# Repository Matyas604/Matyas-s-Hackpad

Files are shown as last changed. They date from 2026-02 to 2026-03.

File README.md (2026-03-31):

# Matyas-s-Hackpad
It has 8 keys (7 switches + rotary encoder switch), a rotary encoder, and an OLED display. Each key is backlit with SK6812 MINI-E LEDs. It uses [QMK](https://qmk.fm/) firmware and VIA.

## CAD Model:
Everything is connected by four M3x16mm screws and M3x5mx4mm heatset inserts. The case is printed in two parts, top and bottom.
<p align="center">
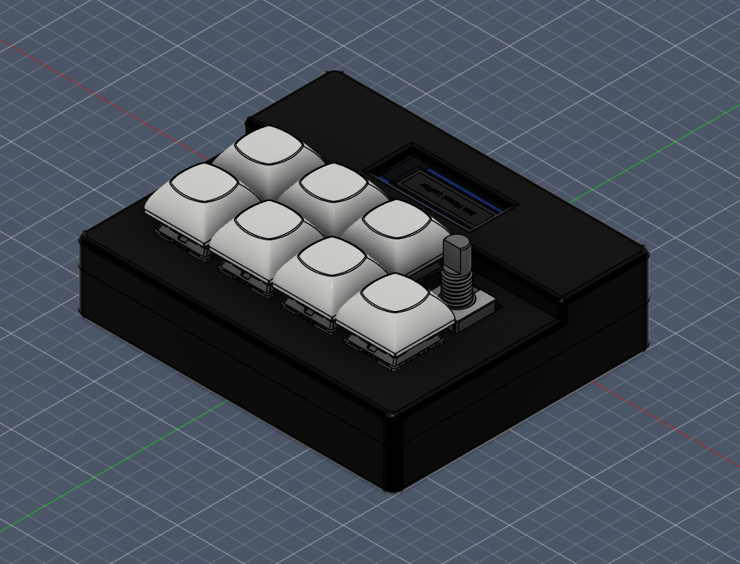
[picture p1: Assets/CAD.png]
Hackpad CAD
  
</p>
<p align="center">
  <strong>Made in Fusion360</strong>
</p>

## PCB:
<p align="center">
  Schematic
</p>
<p align="center">
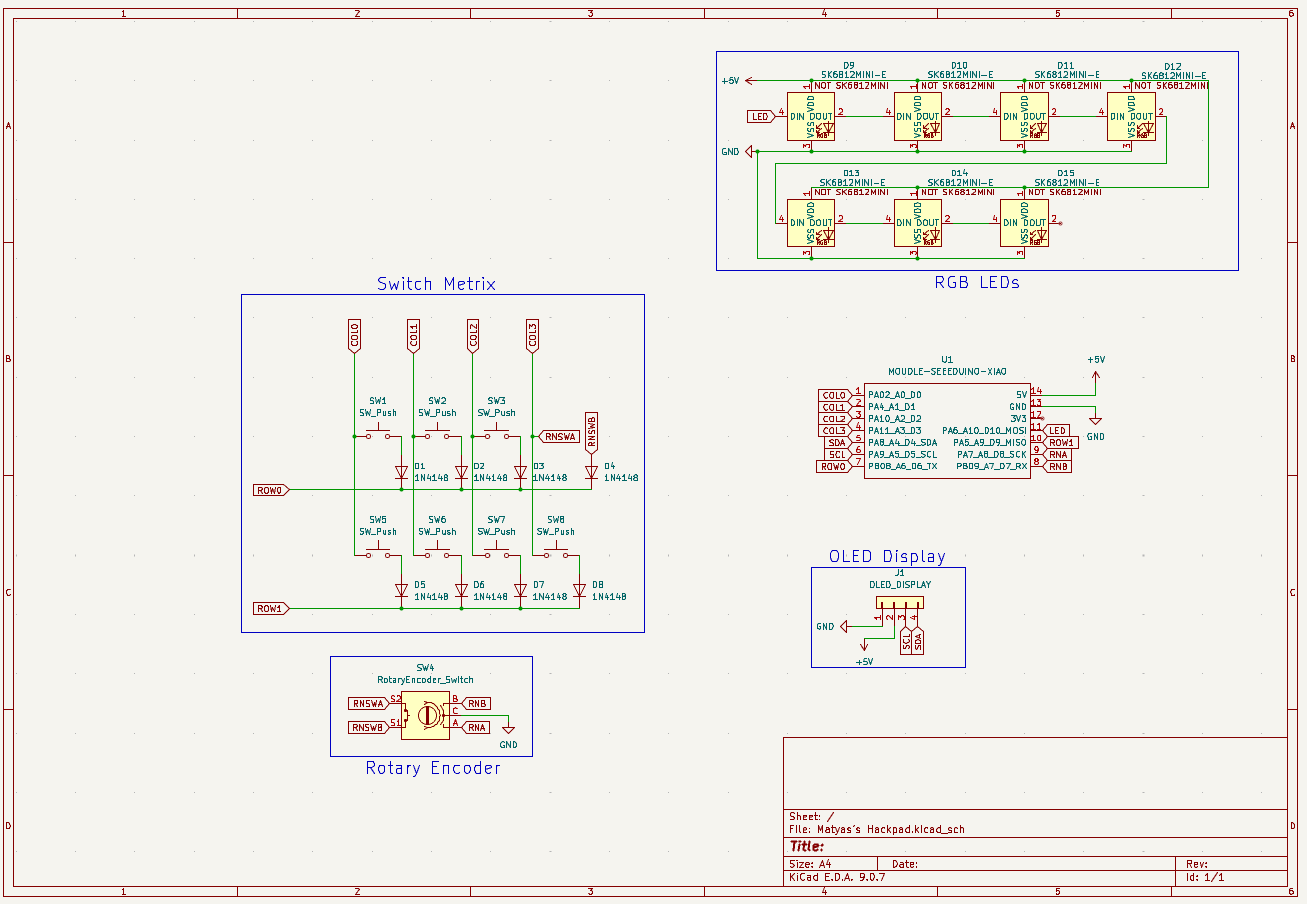
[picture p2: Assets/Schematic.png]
Hackpad schematic
  
</p>
<br>
<p align="center">
  PCB
</p>
<p align="center">
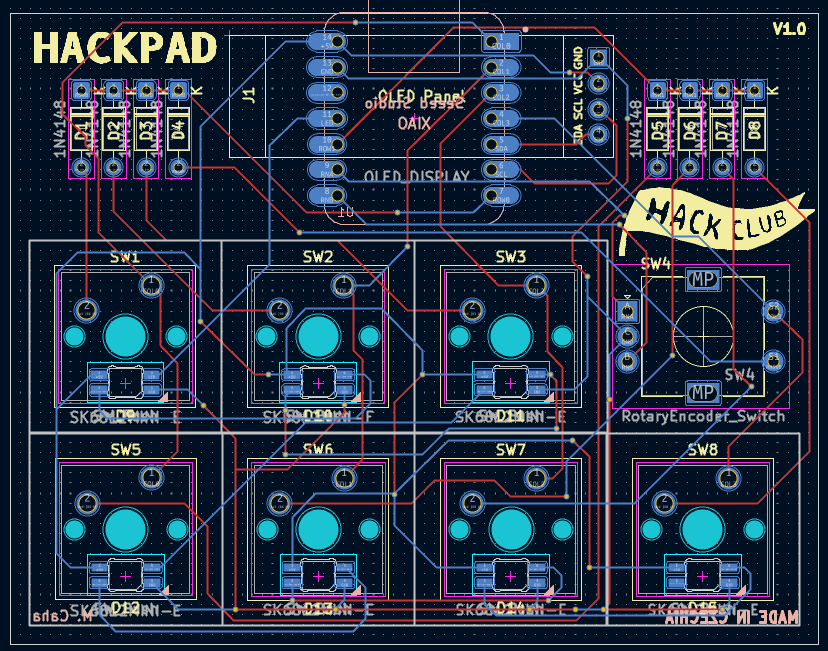
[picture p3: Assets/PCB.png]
Hackpad PCB
  
</p>
<p align="center">
  <strong>Made in KiCad</strong>
</p>

## Case:
<p align="center">
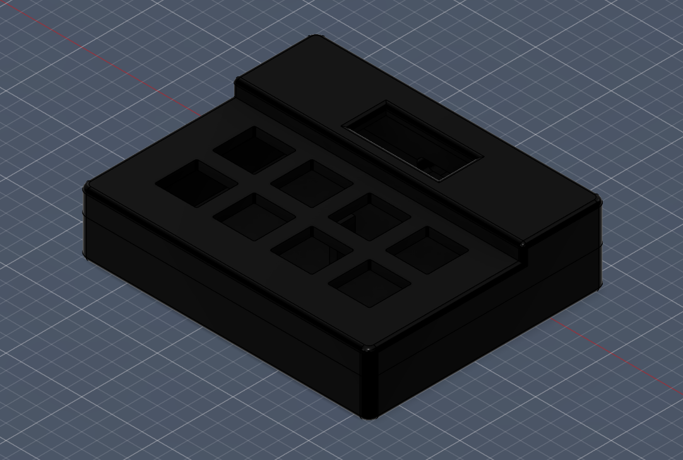
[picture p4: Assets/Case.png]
Hackpad Case
  
</p>
<p align="center">
  <strong>Made in Fusion360</strong>
</p>

## Firmware:
This Hackpad uses [QMK](https://qmk.fm/) firmware. Everything can be controlled in VIA. I have five layers set up, and I can assign anything to each one. I switch between them with a single switch. My layers are Main, Media, HA (shortcuts for Home Assistant), Game, and Other. I can also adjust the effects, speed, brightness, and backlight colors of LEDs directly from VIA. The OLED display shows the name of the current page.
<p align="center">
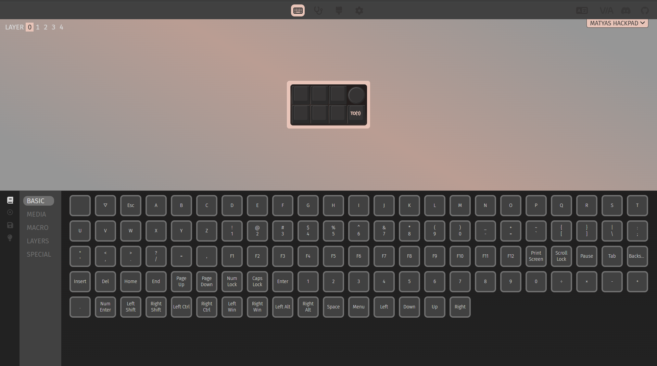
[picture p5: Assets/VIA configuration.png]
VIA Keymap Configuration
  
</p>

<p align="center">
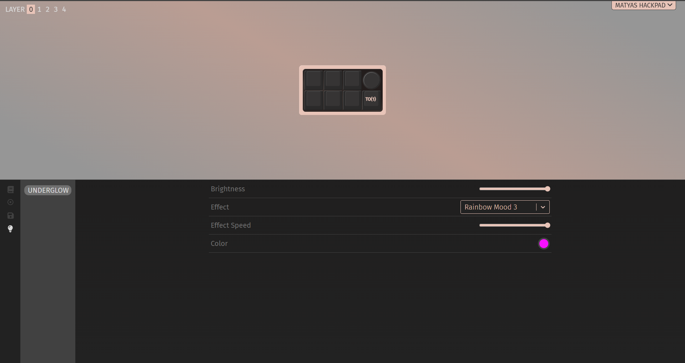
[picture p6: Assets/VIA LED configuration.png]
VIA Underglow Lighting
  
</p>

## Final result:
<p align="center">
  Hackpad Final
  Hackpad Final
</p>
<p align="center">
  <a href="https://www.youtube.com/shorts/VJYHFeJ_mRk">
    🎬 <b>HACKPAD DEMO HERE</b> 🎬
  </a>
</p>
I really enjoyed designing and building the hackpad. It was the very first project I designed from start to finish. I learned how to use Fusion and create PCBs in KiCAD. There were a few mistakes in the model, but they weren’t that big. I made only one mistake during assembly: I soldered the rotary encoder on the other side of the board, and when I desoldered it, I snapped off a leg, but there were two in the kit, so it was fine. The programming was a bit difficult, but in the end, I managed to do what I wanted. 

## BOM:
Here is everything you need to create this Hackpad:
| Component | Amount |
| :--- | :---: |
| **Seeed XIAO RP2040** | 1x |
| **MX-Style switches** | 7x |
| **1N4148 Diodes** | 8x | 
| **EC11 Rotary encoder** | 1x |
| **0.91 inch OLED display** | 1x |
| **DSA keycaps** | 7x |
| **SK6812 MINI-E LED** | 7x |
| **M3x16mm screw** | 4x |
| **M3x5mx4mm heatset insert** | 4x |
| **Case** (2 printed parts) | 1x |
| **PCB** | 1x |

<hr>

<p align="center">
  Made with ❤️ by <a href="https://github.com/Matyas604">@Matyas604</a>
</p>

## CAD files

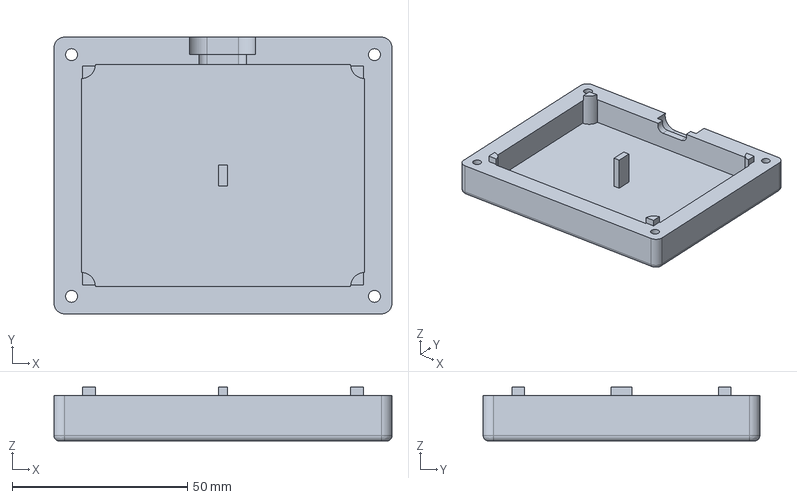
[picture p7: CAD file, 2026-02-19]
Production/Bottom part.step
96.5 x 79.0 x 15.4 mm

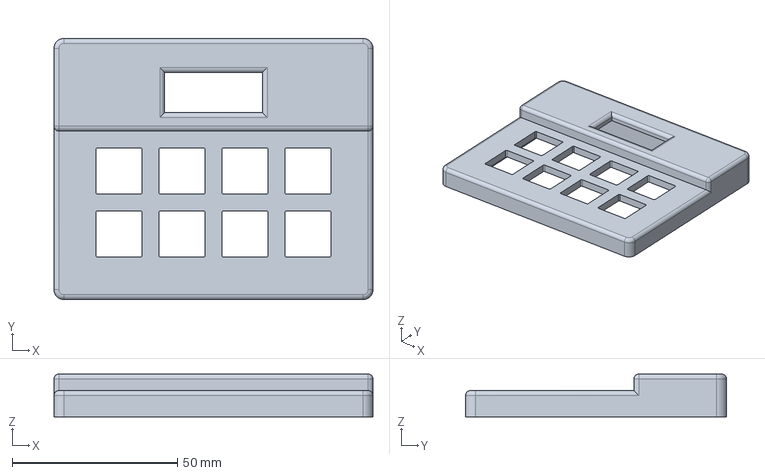
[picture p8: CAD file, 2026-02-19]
Production/Top part.step
96.4 x 79.0 x 13.0 mm

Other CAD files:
CAD/Matyas's Hackpad V1.step

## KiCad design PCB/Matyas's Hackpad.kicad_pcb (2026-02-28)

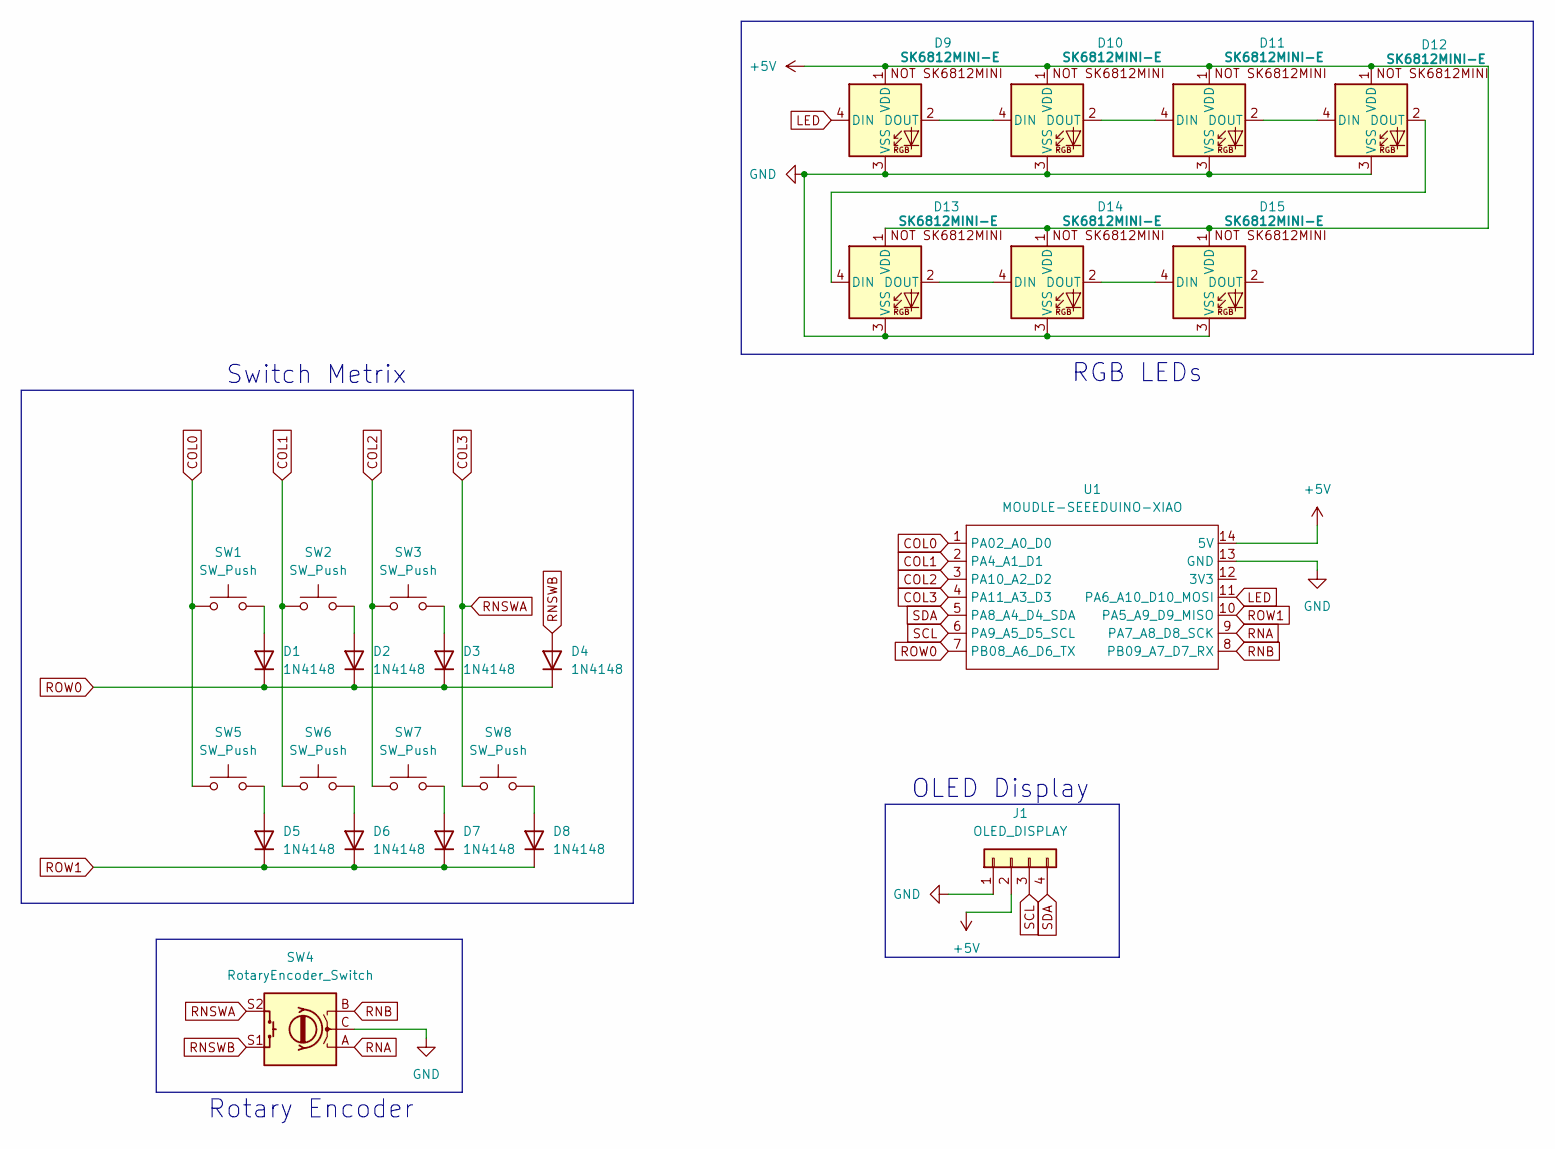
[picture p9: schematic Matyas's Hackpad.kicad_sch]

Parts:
D1, D2, D3, D4, D5, D6, D7, D8: 1N4148; D_DO-35_SOD27_P7.62mm_Horizontal
D9, D10, D11, D12, D13, D14, D15: SK6812MINI-E; SK6812MINI-E_fixed
J1: OLED_DISPLAY; SSD1306-0.91-OLED-4pin-128x32
SW1, SW2, SW3, SW5, SW6, SW7, SW8: SW_Push; SW_Cherry_MX_1.00u_PCB
SW4: RotaryEncoder_Switch; RotaryEncoder_Alps_EC11E-Switch_Vertical_H20mm
U1: MOUDLE-SEEEDUINO-XIAO; XIAO-Generic-Hybrid-14P-2.54-21X17.8MM

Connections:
+5V: D9.1 (VDD), D10.1 (VDD), D11.1 (VDD), D12.1 (VDD), D13.1 (VDD), D14.1 (VDD), D15.1 (VDD), J1.2, U1.14 (5V)
COL0: SW1.1, SW5.1, U1.1 (PA02_A0_D0)
COL1: SW2.1, SW6.1, U1.2 (PA4_A1_D1)
COL2: SW3.1, SW7.1, U1.3 (PA10_A2_D2)
COL3: SW4.S2, SW8.1, U1.4 (PA11_A3_D3)
GND: D9.3 (VSS), D10.3 (VSS), D11.3 (VSS), D12.3 (VSS), D13.3 (VSS), D14.3 (VSS), D15.3 (VSS), J1.1, SW4.C, U1.13 (GND)
LED: D9.4 (DIN), U1.11 (PA6_A10_D10_MOSI)
unnamed: D1.2 (A), SW1.2
unnamed: D2.2 (A), SW2.2
unnamed: D3.2 (A), SW3.2
unnamed: D5.2 (A), SW5.2
unnamed: D6.2 (A), SW6.2
unnamed: D7.2 (A), SW7.2
unnamed: D8.2 (A), SW8.2
unnamed: D9.2 (DOUT), D10.4 (DIN)
unnamed: D10.2 (DOUT), D11.4 (DIN)
unnamed: D11.2 (DOUT), D12.4 (DIN)
unnamed: D12.2 (DOUT), D13.4 (DIN)
unnamed: D13.2 (DOUT), D14.4 (DIN)
unnamed: D14.2 (DOUT), D15.4 (DIN)
RNA: SW4.A, U1.9 (PA7_A8_D8_SCK)
RNB: SW4.B, U1.8 (PB09_A7_D7_RX)
RNSWB: D4.2 (A), SW4.S1
ROW0: D1.1 (K), D2.1 (K), D3.1 (K), D4.1 (K), U1.7 (PB08_A6_D6_TX)
ROW1: D5.1 (K), D6.1 (K), D7.1 (K), D8.1 (K), U1.10 (PA5_A9_D9_MISO)
SCL: J1.3, U1.6 (PA9_A5_D5_SCL)
SDA: J1.4, U1.5 (PA8_A4_D4_SDA)

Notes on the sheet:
RGB LEDs
Switch Metrix
OLED Display
Rotary Encoder

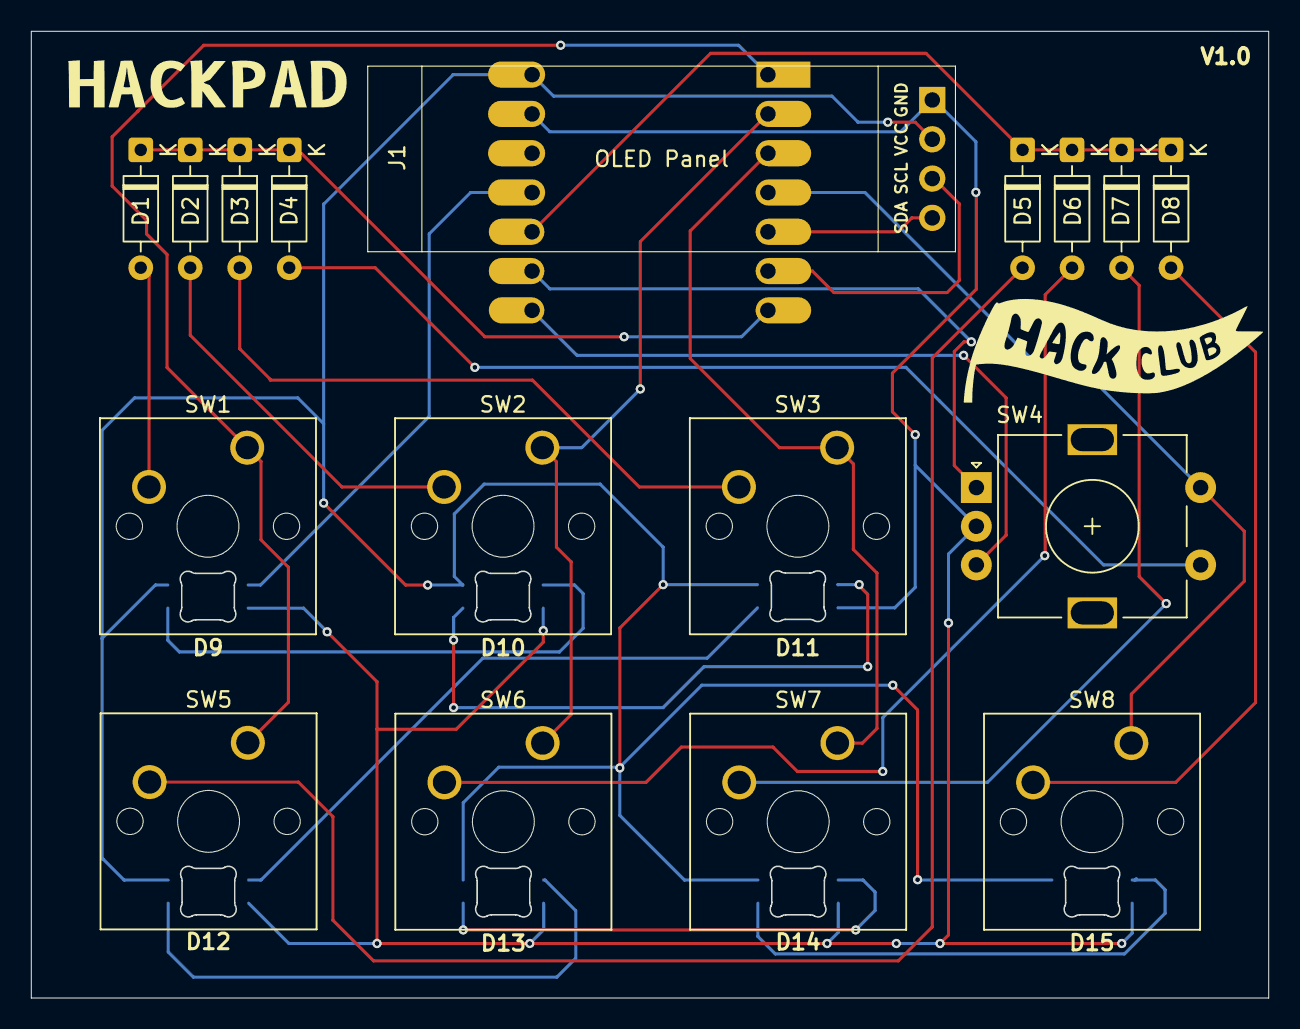
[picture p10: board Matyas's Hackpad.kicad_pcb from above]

Board: 2 copper layers, 80.0 x 62.5 mm, 25 parts (1 on the bottom side), 27 nets.

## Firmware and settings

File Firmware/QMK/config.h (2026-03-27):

#pragma once

#define I2C_DRIVER I2CD1
#define I2C1_SDA_PIN GP6
#define I2C1_SCL_PIN GP7
#define OLED_TIMEOUT 300000
#define WS2812_DI_PIN GP3
#define WS2812_BYTE_ORDER WS2812_BYTE_ORDER_GRB
#define RGBLIGHT_LIMIT_VAL 120
#define RGBLIGHT_HUE_STEP 8
#define RGBLIGHT_SAT_STEP 8
#define RGBLIGHT_VAL_STEP 8
#define DYNAMIC_KEYMAP_LAYER_COUNT 5
#define VENDOR_ID 0x1234
#define PRODUCT_ID 0x0001
#define RGBLIGHT_EFFECT_BREATHING
#define RGBLIGHT_EFFECT_RAINBOW_MOOD
#define RGBLIGHT_EFFECT_RAINBOW_SWIRL
#define RGBLIGHT_EFFECT_SNAKE
#define RGBLIGHT_EFFECT_KNIGHT
#define RGBLIGHT_EFFECT_CHRISTMAS
#define RGBLIGHT_EFFECT_STATIC_GRADIENT

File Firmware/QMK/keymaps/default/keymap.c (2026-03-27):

#include QMK_KEYBOARD_H

const uint16_t PROGMEM keymaps[][MATRIX_ROWS][MATRIX_COLS] = {
    // Main
    [0] = LAYOUT(KC_TRNS, KC_TRNS, KC_TRNS, KC_TRNS, KC_TRNS, KC_TRNS, KC_TRNS, KC_TRNS),
    // Media
    [1] = LAYOUT(KC_TRNS, KC_TRNS, KC_TRNS, KC_TRNS, KC_TRNS, KC_TRNS, KC_TRNS, KC_TRNS),
    // Home assistant
    [2] = LAYOUT(KC_TRNS, KC_TRNS, KC_TRNS, KC_TRNS, KC_TRNS, KC_TRNS, KC_TRNS, KC_TRNS),
    // Game
    [3] = LAYOUT(KC_TRNS, KC_TRNS, KC_TRNS, KC_TRNS, KC_TRNS, KC_TRNS, KC_TRNS, KC_TRNS),
    // Other
    [4] = LAYOUT(KC_TRNS, KC_TRNS, KC_TRNS, KC_TRNS, KC_TRNS, KC_TRNS, KC_TRNS, KC_TRNS)
};

#ifdef ENCODER_MAP_ENABLE
const uint16_t PROGMEM encoder_map[][NUM_ENCODERS][2] = {
    [0] = { ENCODER_CCW_CW(KC_TRNS, KC_TRNS) },
    [1] = { ENCODER_CCW_CW(KC_TRNS, KC_TRNS) },
    [2] = { ENCODER_CCW_CW(KC_TRNS, KC_TRNS) },
    [3] = { ENCODER_CCW_CW(KC_TRNS, KC_TRNS) },
    [4] = { ENCODER_CCW_CW(KC_TRNS, KC_TRNS) } 
};
#endif

#ifdef OLED_ENABLE
oled_rotation_t oled_init_user(oled_rotation_t rotation) { 
    return OLED_ROTATION_180; 
}

bool oled_task_user(void) {

    oled_set_cursor(7, 1); 
    
    uint8_t layer = get_highest_layer(layer_state);
    
    if (layer == 0)      oled_write_P(PSTR("MAIN  "), false);
    else if (layer == 1) oled_write_P(PSTR("MEDIA "), false);
    else if (layer == 2) oled_write_P(PSTR("HA   "), false);
    else if (layer == 3) oled_write_P(PSTR("GAME "), false);
    else if (layer == 4) oled_write_P(PSTR("OTHER   "), false);
    
    return true; 
}
#endif

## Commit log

2026-02-19 Create CAD
2026-02-19 Adding files
    [Matyas's Hackpad V1.step]
2026-02-28 Fix for manufacture
    [Matyas's Hackpad.kicad_pcb]
